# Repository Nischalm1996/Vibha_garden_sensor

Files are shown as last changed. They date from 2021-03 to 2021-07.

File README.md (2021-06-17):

# Vibha_garden_sensor

## GARDEN STATION
| NAME | Pin |
|---|-----|
| SDA | A4  |
| SCL | A5  |
| SOIL | A7  |
| OK | D5  |
| LEFT | D4  |
| RIGHT | D7  |
| BACK | D6  |
| SOUND | A3  |
| DHT11 | D2  |
| TX | D0  |
| RX | D1  |

### MODULES USED
- SOUND (LM393)
- DHT11
- MPU6050 GYROSCOPE
- SOIL MOISTURE
- ESP8266 NODEMCU
- ARDUINO NANO
- NAVIGATION MODULE
- DISPLAY I2C 16*2

###THINGS SPEAK DETAILS
####GMAIL DETAILS
ID- portableevironment@gmail.com
Password- EnvironmentPort@1
https://thingspeak.com/channels/1418539/private_show

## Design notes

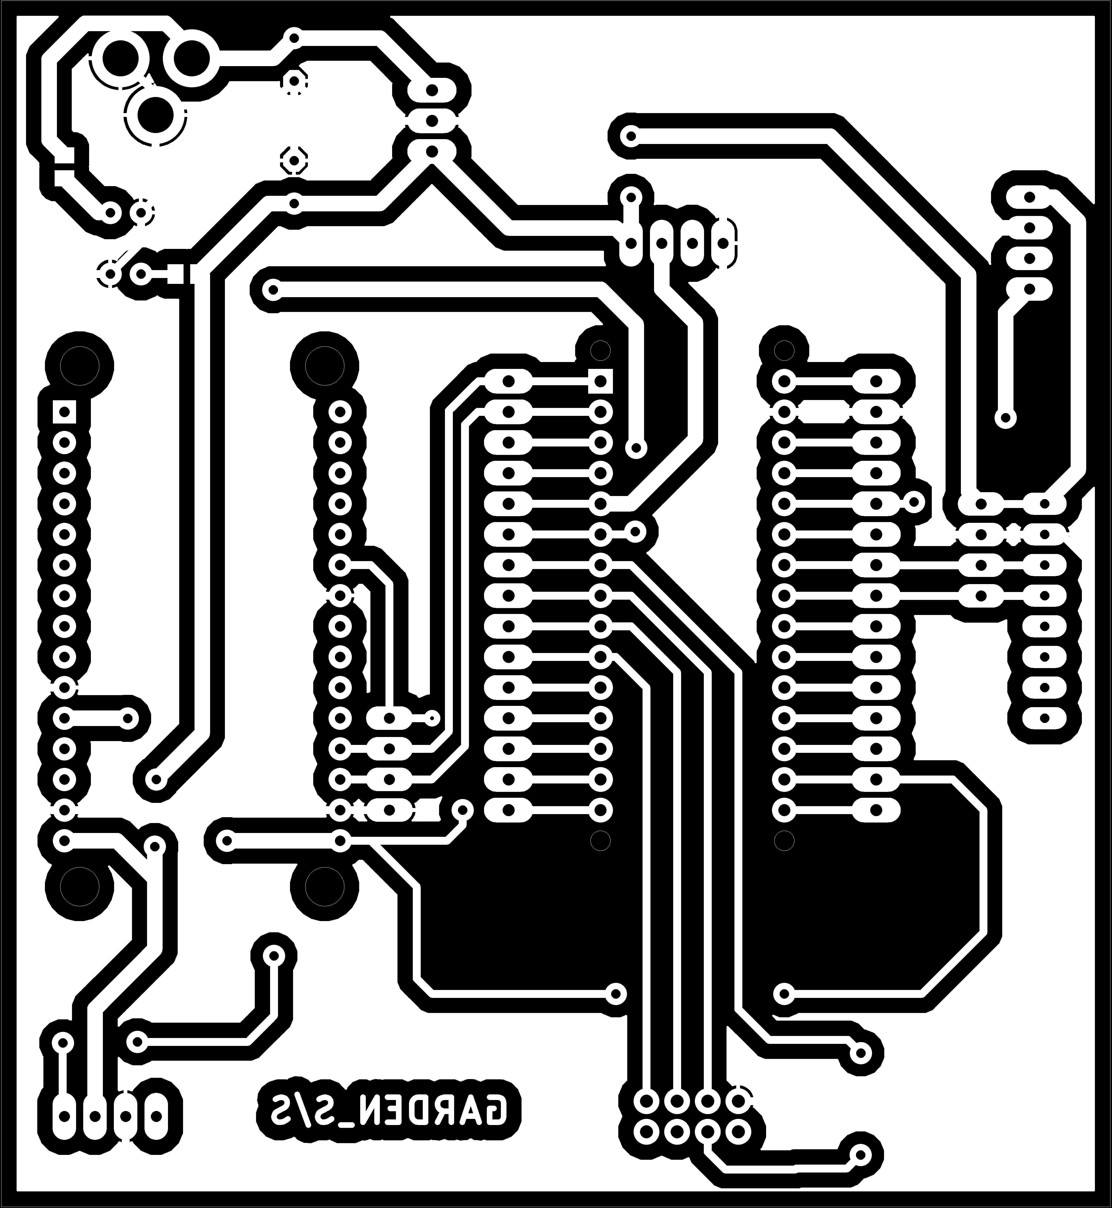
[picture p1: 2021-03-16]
1.PCB/bottom_copper.png

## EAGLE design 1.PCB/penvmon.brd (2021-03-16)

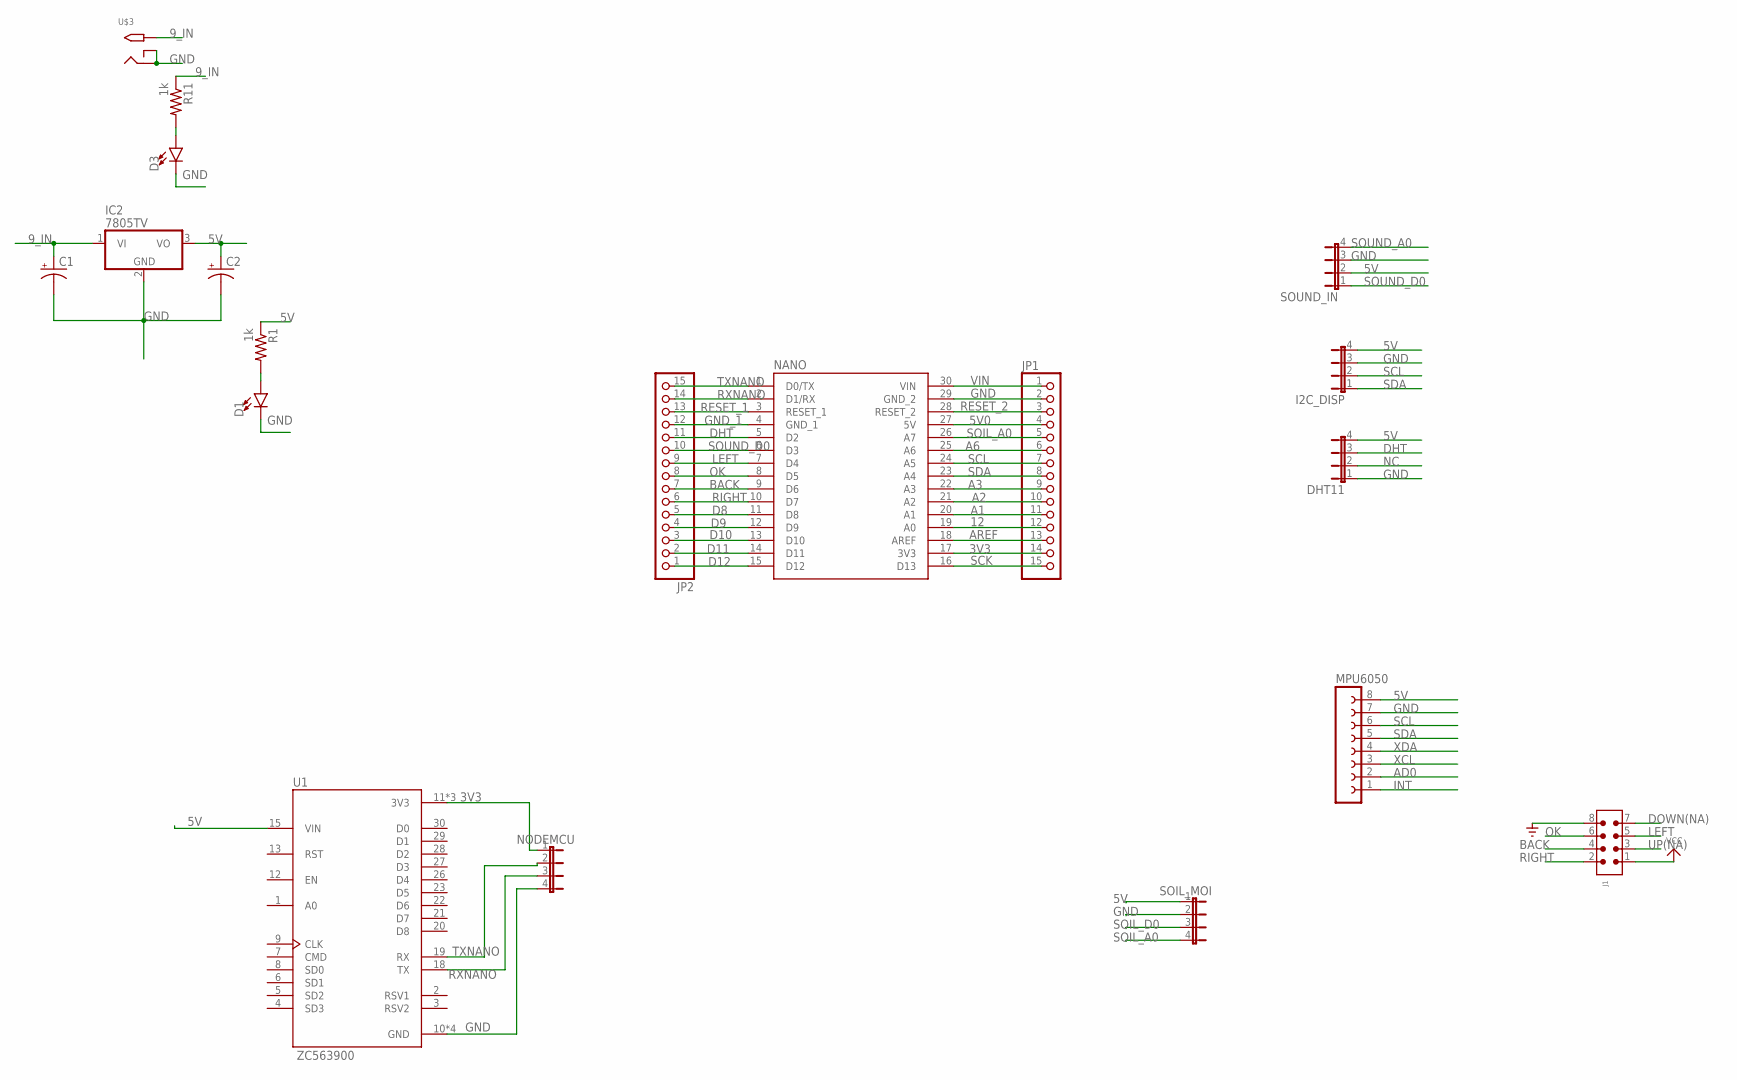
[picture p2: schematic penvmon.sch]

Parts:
C1, C2: CPOL-USE3.5-8; E3,5-8
D1, D3: LED3MM; LED_3MM
DHT11: JP4E; JP4
I2C_DISP: JP4E; JP4
IC2: 7805TV; TO220V
J1: 6120XX21621_61200821621; 61200821621
JP1, JP2: PINHD-1X15; 1X15
MPU6050: FE08-1; FE08
NANO: A000005; MODULE_A000005
NODEMCU: JP4E; JP4
R1, R11: 1k; M0805
SOIL_MOI: JP4E; JP4
SOUND_IN: JP4E; JP4
U1: ZC563900; MODULE_ZC563900
U$3: 2.1MMJACKTHM; PJ-102A

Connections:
3V3: JP1.14, NANO.17 (3V3), NODEMCU.1, U1.11 (3V3), U1.16 (3V3), U1.25 (3V3)
5V: C2.+, DHT11.4, I2C_DISP.4, IC2.3 (VO), MPU6050.8, R1.1, SOIL_MOI.1, SOUND_IN.2, U1.15 (VIN)
5V0: JP1.4, NANO.27 (5V)
9_IN: C1.+, IC2.1 (VI), R11.1, U$3.TIP
12: JP1.12, NANO.19 (A0)
A1: JP1.11, NANO.20 (A1)
A2: JP1.10, NANO.21 (A2)
A3: JP1.9, NANO.22 (A3)
A6: JP1.6, NANO.25 (A6)
AD0: MPU6050.2
AREF: JP1.13, NANO.18 (AREF)
BACK: J1.4, JP2.7, NANO.9 (D6)
D8: JP2.5, NANO.11 (D8)
D9: JP2.4, NANO.12 (D9)
D10: JP2.3, NANO.13 (D10)
D11: JP2.2, NANO.14 (D11)
D12: JP2.1, NANO.15 (D12)
DHT: DHT11.3, JP2.11, NANO.5 (D2)
DOWN(NA): J1.7
GND: C1.-, C2.-, D1.K (C), D3.K (C), DHT11.1, I2C_DISP.3, IC2.2 (GND), J1.8, JP1.2, MPU6050.7, NANO.29 (GND_2), NODEMCU.4, SOIL_MOI.2, SOUND_IN.3, U1.10 (GND), U1.14 (GND), U1.17 (GND), U1.24 (GND), U$3.RING, U$3.RING_SW
GND_1: JP2.12, NANO.4 (GND_1)
INT: MPU6050.1
LEFT: J1.5, JP2.9, NANO.7 (D4)
unnamed: D3.A, R11.2
unnamed: D1.A, R1.2
NC: DHT11.2
OK: J1.6, JP2.8, NANO.8 (D5)
RESET_1: JP2.13, NANO.3 (RESET_1)
RESET_2: JP1.3, NANO.28 (RESET_2)
RIGHT: J1.2, JP2.6, NANO.10 (D7)
RXNANO: JP2.14, NANO.2 (D1/RX), NODEMCU.3, U1.18 (TX)
SCK: JP1.15, NANO.16 (D13)
SCL: I2C_DISP.2, JP1.7, MPU6050.6, NANO.24 (A5)
SDA: I2C_DISP.1, JP1.8, MPU6050.5, NANO.23 (A4)
SOIL_A0: JP1.5, NANO.26 (A7), SOIL_MOI.4
SOIL_D0: SOIL_MOI.3
SOUND_A0: SOUND_IN.4
SOUND_D0: JP2.10, NANO.6 (D3), SOUND_IN.1
TXNANO: JP2.15, NANO.1 (D0/TX), NODEMCU.2, U1.19 (RX)
UP(NA): J1.3
VCC: J1.1
VIN: JP1.1, NANO.30 (VIN)
XCL: MPU6050.3
XDA: MPU6050.4

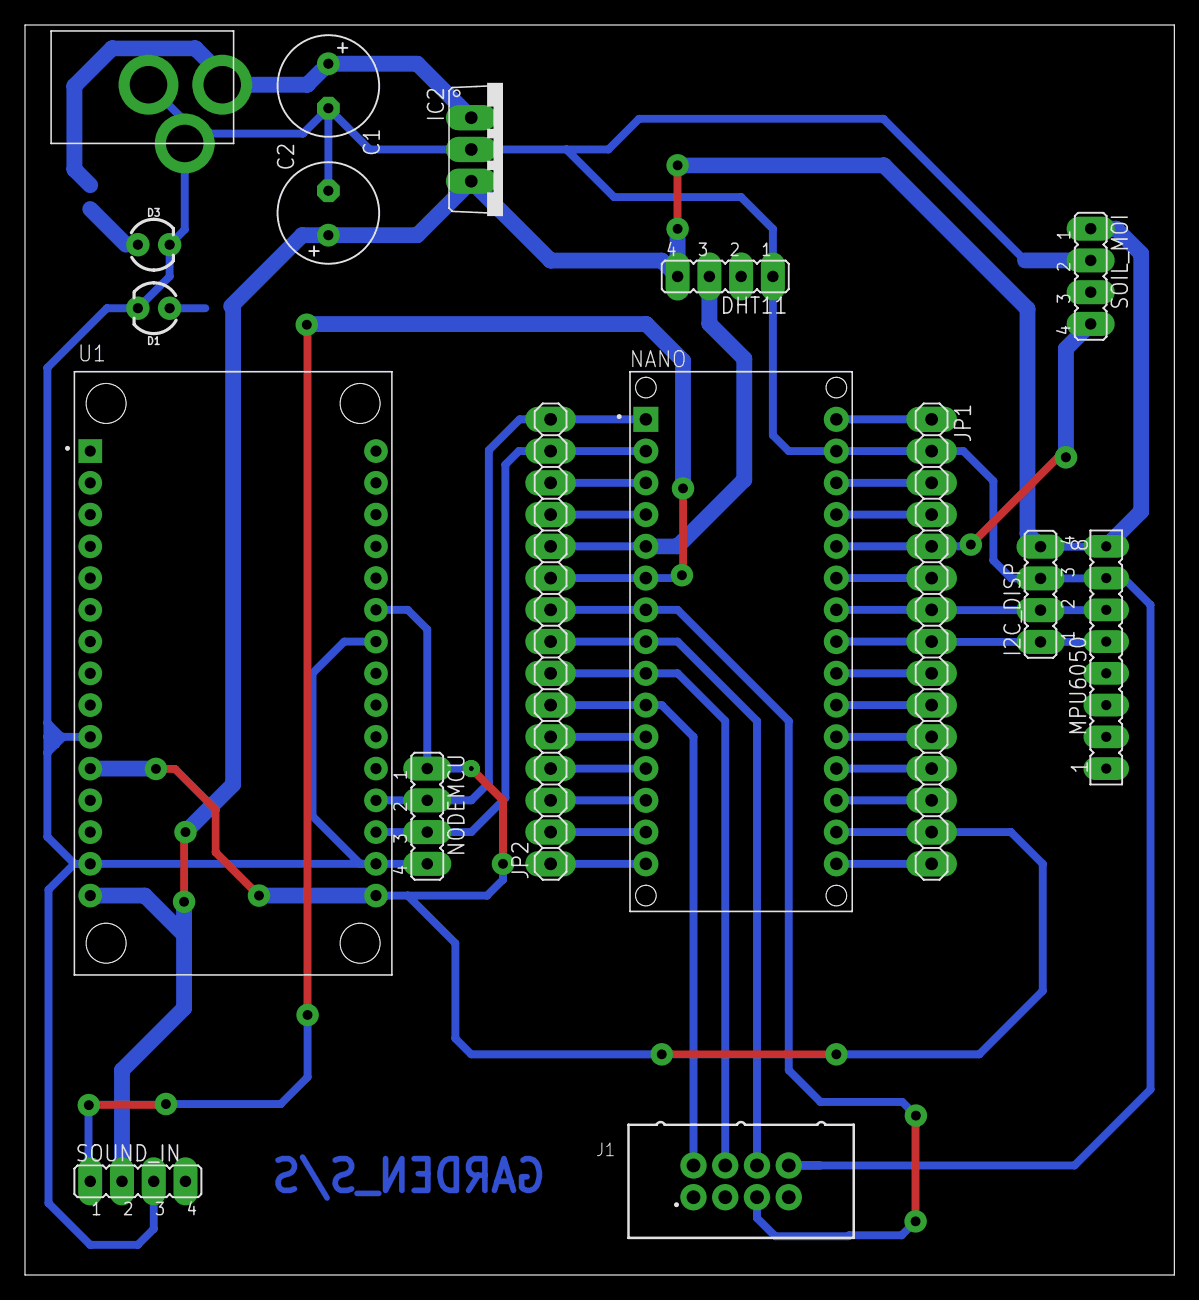
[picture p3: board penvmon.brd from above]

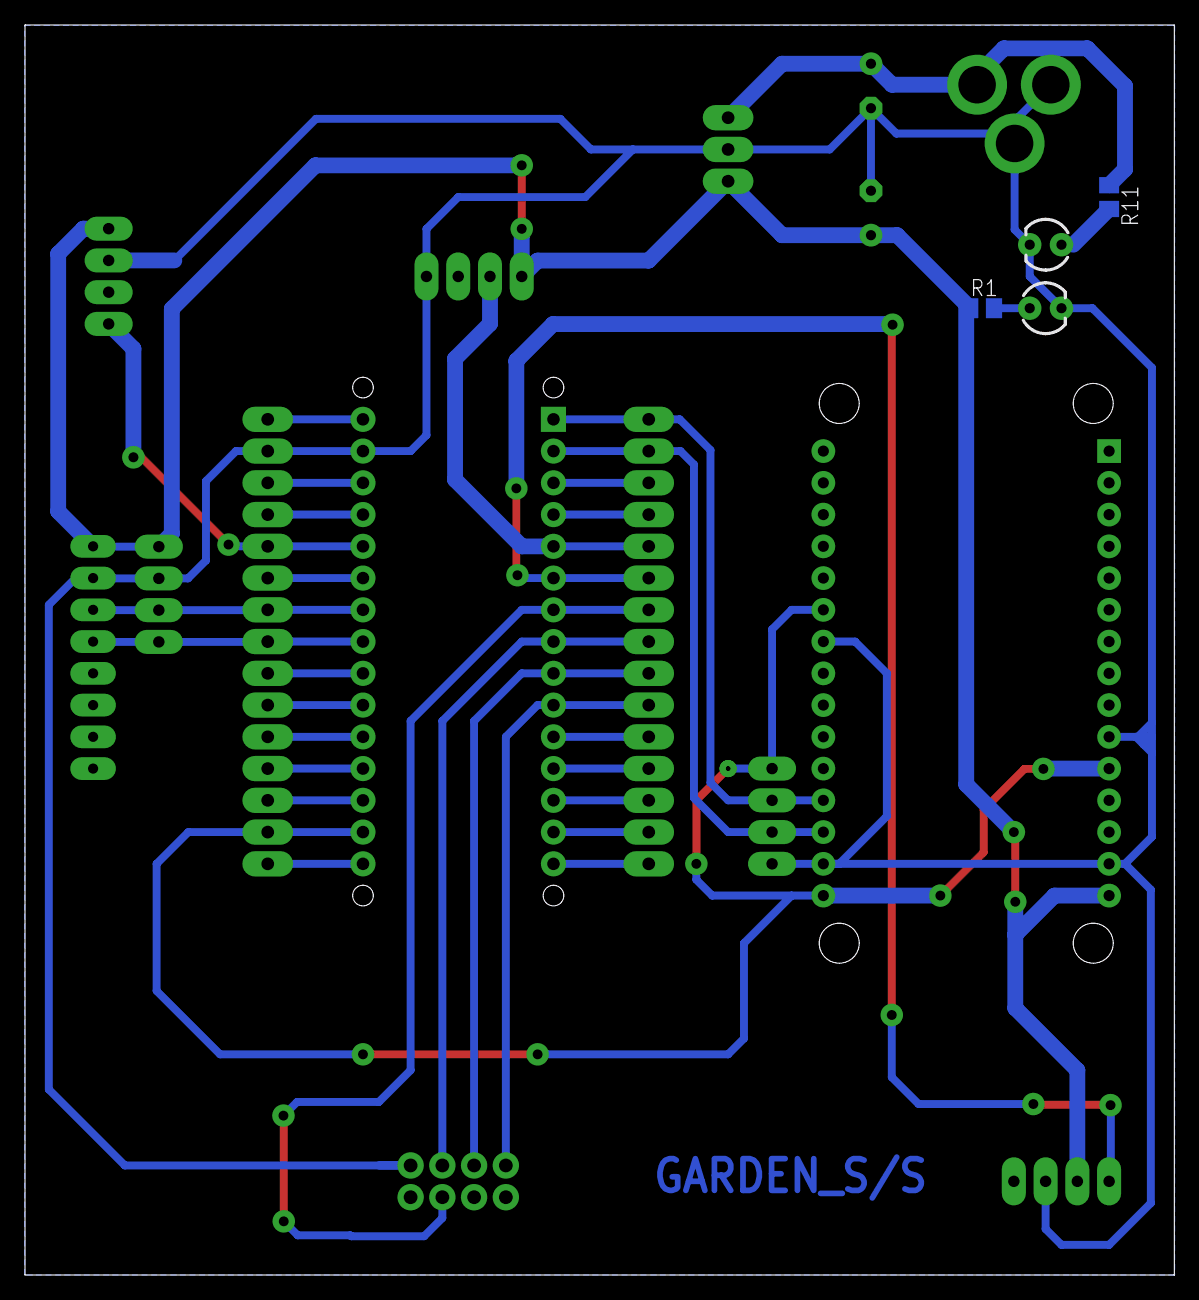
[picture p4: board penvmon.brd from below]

Board: 2 copper layers, 91.9 x 100.0 mm, 19 parts (2 on the bottom side), 34 nets.

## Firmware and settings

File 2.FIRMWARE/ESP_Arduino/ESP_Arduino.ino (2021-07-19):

#include<SoftwareSerial.h>
#include <ESP8266WiFi.h>
#include "secrets.h"
#include "ThingSpeak.h" // always include thingspeak header file after other header files and custom macros

char ssid[] = SECRET_SSID;   // your network SSID (name)
char pass[] = SECRET_PASS;   // your network password
int keyIndex = 0;            // your network key Index number (needed only for WEP)
WiFiClient  client;

unsigned long myChannelNumber = SECRET_CH_ID;
const char * myWriteAPIKey = SECRET_WRITE_APIKEY;


String myStatus = "";

byte flag;

char c;
String dataIn;
int8_t indexofA, indexofB, indexofC, indexofD, indexofE, indexofS, indexofF, a, b;
String temp_cel, humid, soil_moisture, _noise,
       gyrox, gyroy;




void setup() {
  // put your setup code here, to run once:
  Serial.begin(9600);
  WiFi.mode(WIFI_STA);
  WiFi.begin(ssid, pass);

  while (WiFi.status() != WL_CONNECTED) {
    delay(500);
    Serial.print(".");
  }

  Serial.println("");
  Serial.println("WiFi connected");
  Serial.println("IP address: ");
  Serial.println(WiFi.localIP());
    ThingSpeak.begin(client);

}
unsigned long time_now;
void loop() {
  // put your main code here, to run repeatedly:
  

  if (millis() < (time_now + 20000)) {
    flag = 0;

  }
  else {
    flag = 1;
    time_now  = millis();

    //Serial.print(".");
  }
  if (flag == 1)
  {
    //flushy();

    readSerialData();

    sendToThingsSpeak();
    flag = 0;
    time_now = millis();
  }
}
//////////////////////////////////////////////////////////////////////////////////
void parse_the_data()
{
  indexofS = dataIn.indexOf("S");
  indexofA = dataIn.indexOf("A");
  indexofB = dataIn.indexOf("B");
  indexofC = dataIn.indexOf("C");
  indexofD = dataIn.indexOf("D");
  indexofE = dataIn.indexOf("E");
  indexofF = dataIn.indexOf("F");

  temp_cel = dataIn.substring (indexofS + 1 , indexofA);
  humid = dataIn.substring (indexofA + 1, indexofB);
  soil_moisture = dataIn.substring (indexofB + 1, indexofC);
  _noise = dataIn.substring (indexofC + 1, indexofD);
  gyrox = dataIn.substring (indexofD + 1, indexofE);
  gyroy = dataIn.substring (indexofE + 1, indexofF);
}

void readSerialData()
{
  flushy();
  Serial.println('*');
  delay(100);
  while (Serial.available() > 0)
  {
    c = Serial.read();
    if (c == '\n') {
      break;
    }
    else    {
      dataIn = dataIn + c;
    }
    //Serial.println(c);

  }
  Serial.println(dataIn);
  if (c == '\n')
  {
    parse_the_data();
  }
  c = 0;
  dataIn = "";
  //  Serial.println("temp_cel=" + temp_cel);
  //  Serial.println("humidity=" + humid);
  //  Serial.println("Soil Moisture=" + soil_moisture);
  //  Serial.println("Noise=" + _noise);
  //  Serial.println("Gyro x axis=" + gyrox);
  //  Serial.println("Gyro y axis=" + gyroy);
}

void sendToThingsSpeak()
{
  Serial.println("temp_cel=" + temp_cel);
  Serial.println("humidity=" + humid);
  Serial.println("Soil Moisture=" + soil_moisture);
  Serial.println("Noise=" + _noise);
  Serial.println("Gyro x axis=" + gyrox);
  Serial.println("Gyro y axis=" + gyroy);
  ThingSpeak.setField(1, temp_cel);
  ThingSpeak.setField(2, humid);
  ThingSpeak.setField(3, soil_moisture);
  ThingSpeak.setField(4, _noise);
  ThingSpeak.setField(5, gyrox);
  ThingSpeak.setField(6, gyroy);
  ThingSpeak.setStatus(myStatus);

  // write to the ThingSpeak channel
  int x = ThingSpeak.writeFields(myChannelNumber, myWriteAPIKey);
  if (x == 200) {
    Serial.println("Channel update successful.");
  }
  else {
    Serial.println("Problem updating channel. HTTP error code " + String(x));
  }
}
void flushy()
{
  while (Serial.available())
    Serial.read();
}

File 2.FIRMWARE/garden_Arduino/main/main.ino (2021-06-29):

#include "Arduino.h"
#include "dht11.h"
#include "sound.h"
#include "soilMoisture.h"
#include "mpu.h"
#include "Button.h"
#include <LiquidMenu.h>
#include <LiquidCrystal_I2C.h>
//push
//OK  D5
//LEFT  D7
//RIGHT D4

const bool pullup = false;

Button left(7, pullup);
Button right(4, pullup);
Button enter(5, pullup);


dhtClass temper;
sound Noise;
soilMoisture moisture;
mpuClass angle;

struct allValues {
  float temp_cel;
  float temp_fah;
  float humid;
  int soil_moisture;
  int sound;
  int gyrox;
  int gyroy;
  int gyroz;
};
allValues toEsp = {temp, fahren, 0, 0, 0, 0, 0, 0};

LiquidCrystal_I2C lcd(0x27, 16, 2);
LiquidLine welcome_line1(1, 0, "Environment");
LiquidLine welcome_line2(1, 1, "Monitor System");
LiquidScreen welcome_screen(welcome_line1, welcome_line2);
LiquidLine temp1(1, 0, "Temp(Cel):", toEsp.temp_cel);
LiquidLine temp2(1, 1, "Humidity:", toEsp.humid);
LiquidScreen temp_screen(temp1, temp2);
LiquidLine _moisture(1, 0, "Moisture: ", toEsp.soil_moisture);
LiquidLine _Noise(1, 1, "Noise: ", toEsp.sound);
LiquidScreen Screen2(_moisture, _Noise);;
LiquidLine gyrox(1, 0, "Elevation X:", toEsp.gyrox);
LiquidLine gyroy(1, 1, "Elevation Y:", toEsp.gyroy);
LiquidScreen screen3(gyrox, gyroy);

LiquidMenu menu(lcd);

void setup() {
  Serial.begin(9600);

  lcd.init();
  lcd.backlight();
  delay(500);
  lcd.noBacklight();
  delay(500);
  lcd.backlight();
  // Menu initialization.
  menu.init();
  // This is the method used to add a screen object to the menu.
  menu.add_screen(welcome_screen);
  menu.add_screen(temp_screen);
  menu.add_screen(Screen2);
  menu.add_screen(screen3);
  menu.update();
  angle.begin();
  temper.begin();
  delay(500);
  menu.next_screen();
  //Serial.println("Setup done");
}
unsigned int count = 0;
void loop() {
  if (right.check() == LOW)
  {
    // Serial.println(F("RIGHT button pressed"));
    menu.next_screen();
  }
  if (left.check() == LOW)
  {
    //Serial.println(F("LEFT button pressed"));
    menu.previous_screen();
  }
  if (enter.check() == LOW)
  {
    //Serial.println(F("ENTER button pressed"));
    menu.switch_focus();
  }
  toEsp = {temp, fahren, humid, moisture.getMoisturePercentage(), Noise.getNoisePercentage(), xaxis, yaxis, zaxis};
  //  Serial.print("celcius: "); Serial.print(toEsp.temp_cel); Serial.print(' ');
  //  Serial.print("Fahreheit: "); Serial.print(toEsp.temp_fah); Serial.print(' ');
  //  Serial.print("Humid: "); Serial.print(toEsp.humid); Serial.println("");
  //  Serial.print("x: "); Serial.print(toEsp.gyrox); Serial.print(' ');
  //  Serial.print("y: "); Serial.print(toEsp.gyroy); Serial.print(' ');
  //  Serial.print("z: "); Serial.print(toEsp.gyroz); Serial.println("");
  //  Serial.print("soil: "); Serial.println(toEsp.soil_moisture);
  //  Serial.print("sound: "); Serial.println(toEsp.sound);
  //  delay(50);

  while (Serial.available() > 0)
  {
    char c = Serial.read();
    if (c == '*')
    {
      toEsp = {temp, fahren, humid, moisture.getMoisturePercentage(), Noise.getNoisePercentage(), xaxis, yaxis, zaxis};
      Serial.print("S"); Serial.print(toEsp.temp_cel); Serial.print("A");
      Serial.print(toEsp.humid); Serial.print("B");
      Serial.print(toEsp.soil_moisture); Serial.print("C");
      Serial.print(toEsp.sound); Serial.print("D");
      Serial.print(toEsp.gyrox); Serial.print("E");
      Serial.print(toEsp.gyroy); Serial.println("F"); Serial.print("\n");
    }
  }
  count = count + 1;
  //Serial.print(".");
  if (count >= 1000) {
    temper.updateTemp();
    angle.updateAngles();
    toEsp = {temp, fahren, humid, moisture.getMoisturePercentage(), Noise.getNoisePercentage(), xaxis, yaxis, zaxis};
    //Serial.println("update");
    menu.update();




    count = 0;
  }

}

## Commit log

2021-03-12 changed Placement- routing and check needed
    [penvmon.brd]
2021-03-13 vibha_layout_done
    kindly check the layout once
    [penvmon.brd, penvmon.sch]
2021-03-13 just_a_little_correction_vibha_project
    all the sensors are added and designed
    [penvmon.brd, penvmon.sch]
2021-03-14 made layout changes
    [penvmon.brd, penvmon.sch]
2021-03-16 added pcb image
    [penvmon.brd, penvmon.sch]
2021-03-16 changed directory structure
    [penvmon.brd, penvmon.sch]
2021-03-16 updated image
    [penvmon.brd]
2021-04-07 PINS_UPDATED
    All the assigned pins as per the design updated
    [penvmon.sch]
2021-04-16 dht11 and soil sensor code
    sensor code created
2021-06-07 working arduino v1
2021-06-17 arduino final v1
2021-06-29 made noise sensor updates
    [main.ino]

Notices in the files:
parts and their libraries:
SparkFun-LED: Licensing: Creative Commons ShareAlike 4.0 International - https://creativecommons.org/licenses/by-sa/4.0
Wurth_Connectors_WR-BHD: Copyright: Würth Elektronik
